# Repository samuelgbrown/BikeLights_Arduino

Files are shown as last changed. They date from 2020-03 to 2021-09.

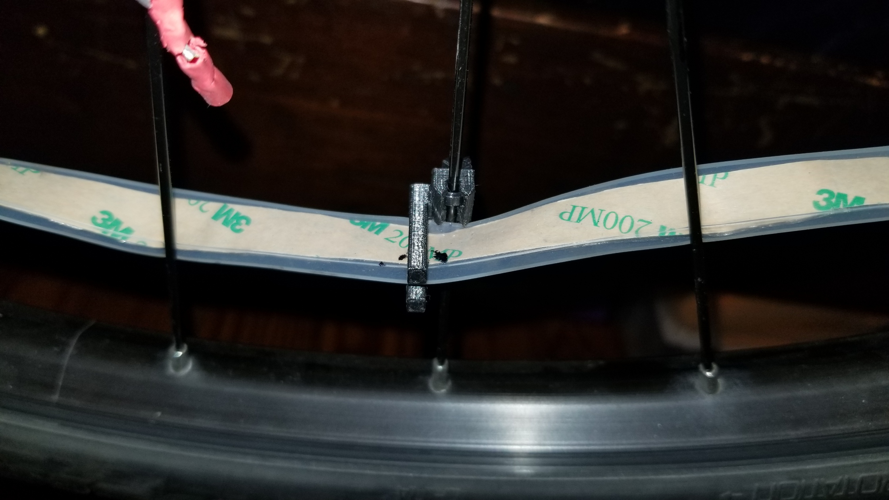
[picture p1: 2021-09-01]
pics/Suggested Guide Marks.jpg

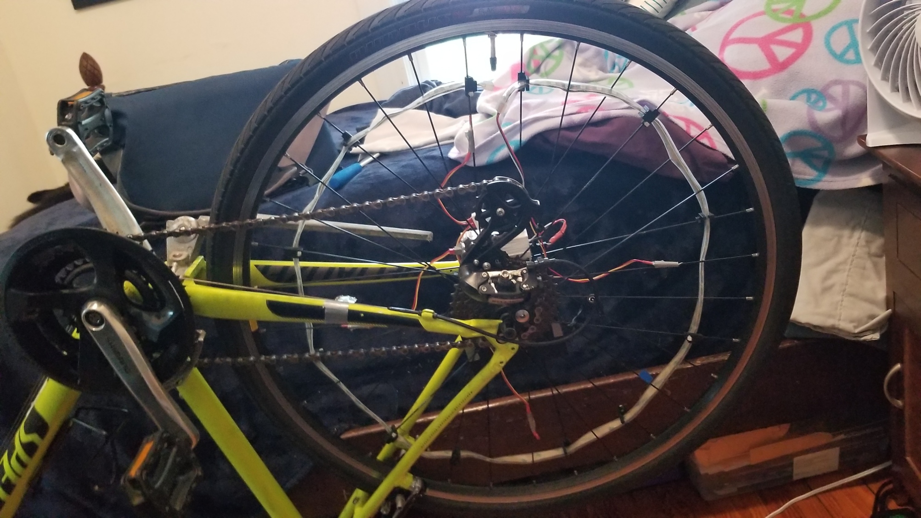
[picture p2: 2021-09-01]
pics/Full System.jpg

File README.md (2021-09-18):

# BikeLights_Arduino

"BikeLights" is a system to generate speed-sensitive light patterns on the edge of a bike's wheel.  It uses an Android device to design a pattern, and an Arduino system to display it on the wheel.

TODO:  Link to video

[See Android portion here](https://github.com/samuelgbrown/BikeLights_Android)

Arduino portion made using [PlatformIO](https://platformio.org/)!

# Theory of Operation
To use BikeLights, the user will design a custom lighting pattern on their Android phone using the Bike Lights app.  The user can then connect to the bluetooth adapter that is mounted on their bike wheel to send the lighting pattern to the LED's on the wheel.  The Arduino board on the wheel-mounted device will then display the designed pattern on the water-proof LED strip mounted along the rim of the wheel, using the information collected by the reed switches.

### 1. Bluetooth Communication protocol
The Android app and Arduino board must be able to communicate via bluetooth, despite the fact that their software is written in different languages.  Additionally, the memory constraints on the Arduino board necessitated writing a custom bluetooth protocol that would minimize the size of the message that must be stored on the Arduino during processing, while still allowing arbitrarily large messages to be received.  [The protocol design can be found here](https://github.com/samuelgbrown/BikeLights_Arduino/blob/master/bluetooth_protocol.txt).

### 2. Speed Detection
The position of the bike wheel is detected using a magnet mounted on the fork of the bike frame and some number N of reed switches mounted in an equiangular fashion around the wheel (see "[Sensors (standard)](https://github.com/samuelgbrown/BikeLights_Arduino/blob/master/Bike_Lights_refined_schem.png)").  The signals from all of the reed switches is treated in the same way, except for one (the "reference").  Each time a reed switch is closed, the signal is filtered through an RC circuit, and one of the hardware flip-flops is closed (one each for standard and reference, see "[RS Flip-Flop](https://github.com/samuelgbrown/BikeLights_Arduino/blob/master/Bike_Lights_refined_schem.png)").  A flip-flop is used so that interrupts are not required.

Once the Speedometer receives a signal from the reed switch (a "tic" or "reference tic"/"rTic"), the new measurement of position and velocity is fed to a [Kalman filter](https://en.wikipedia.org/wiki/Kalman_filter) calculating the wheel's [dead-reckoning](https://en.wikipedia.org/wiki/Dead_reckoning).  The Kalman filter's state variables are the wheel's position, speed, and acceleration in (LEDs, LEDs/s, LEDs/s^2), respectively.  For standard "tic"s, the new position is 1/N fraction of the distance around the wheel.  For "rTic"s, the new position is equal to the next "reference position" (i.e. the location of the wheel when the reference reed switch is aligned with the magnet).  Only one reference reed switch is used to save cost on hardware and space on the PCB.  Once the new measurement is added, the Kalman filter is propogated, and the new estimated position is used to calculate the new lighting position.

### 3. Pattern/Color_ Definition
The lighting on the wheel is defined by two constructs, the Color_ and the Pattern.

The Color_ represents the "paint", and is composed of individual colorObj objects.  Each colorObj represents an actual color (i.e. a hue represented by some combination of red/green/blue light).  A colorObj on its own is represented by a Color_Static object.  A color can then made to change with time (Color_dTime), or with wheel speed (Color_dVel).

The Pattern represents how the Color_ objects are arranged on the wheel.  Each LED can be painted with a Color_.  This pattern can be defined relative to the wheel (wheel speed independent) or relative to the ground (Pattern location changes dependent on wheel speed, to make it appear like it's not moving).  It each case, it can also have some constant angular velocity.  Finally, different patterns can be display in "idle" mode (when the wheel is moving too slowly to be measured by the speedometer) or "main" mode (when the wheel is moving at speed).

# Instructions for Use
Note that BikeLights only works on Android devices.

To set up BikeLights:
1. **Prepare** all materials
    1. **Prepare** Electronics
        1. **Purchase** the items on the Bill of Materials and any listed additional items (see below)
        2. **Prepare** a soldering workstation (including solder, wires, etc)
        3. **Solder** the breadboard according to the [bread board configuration](https://github.com/samuelgbrown/BikeLights_Arduino/blob/master/Bike_Lights_refined_bb.png) (see below for wire color legend), using the [schematic](https://github.com/samuelgbrown/BikeLights_Arduino/blob/master/Bike_Lights_refined_schem.png) for reference.
            1. **Prepare** 2 female 2-pin JST connectors with wires, to be used as connectors for the reed switches
        4. **Prepare** the 1-3 sensor connector adapter
            1. **Print** the [top half](https://github.com/samuelgbrown/BikeLights_Arduino/blob/master/models/1-to-3_Sensor_Connector_Adapter_Top_Final.stl) and [bottom half](https://github.com/samuelgbrown/BikeLights_Arduino/blob/master/models/1-to-3_Sensor_Connector_Adapter_Bottom_Final.stl) of the adapter case.
            2. **Crimp** a single male 2-pin JST connector to 3 female 2-pin JST connectors (in parallel).
            3. **Glue** this circuit of JST connectors in the adapter case (it will be a tight fit, but it will work).
            4. **Test** the connections of the connector adapter (using a test LED, a continuity tester, etc).
        5. **Prepare** the reed switch modules
            1. **Solder** 4 reed switches to wires in an ["inline" configuration](https://github.com/samuelgbrown/BikeLights_Arduino/blob/master/pics/Magnet.jpg) (wires should run along side the reed switch).  The 2 of the modules should have wire lengths of about 8" and 2 should have about 14".  Heat-shrink the exposed wires/solder.
            2. **Crimp** a male 2-pin JST connectors onto each module.
        7. **Prepare** the LED strip
            1. **Measure** the length of LED strip (and, most importantly, the number of LEDs) you will need to surround the circumference of your bike wheel.  Note that the BikeLights looks best when the LEDs are pushed as far towards the circumference of the wheel as possible, and are facing ["outward" from the wheel](https://github.com/samuelgbrown/BikeLights_Arduino/blob/master/pics/Reed%20Switch%20Positioning.jpg).
            2. **Cut** the LED strip to length.
            3. (Optional) **Repair** the waterproofing of the LED strip (using the LED strip waterproofing accessories, listed below), as needed.
            4. **Solder** any wires to the strip, as needed.
            5. (Optional) **Solder** an extension cable for the LED strip wires (a female 3-pin JST connector to a male 3-pin JST connector), that should be about 6" long.
    2. **Prepare** Arduino Software
        1. **Clone** this repo, and open in [PlatformIO](https://platformio.org/)
        2. **Customize** the [definitions in the software](https://github.com/samuelgbrown/BikeLights_Arduino/blob/master/include/Definitions.h#L65).  Specifically, set the number of reed switches you will use around the wheel (NUMSWITCHES), the number of LEDs you measured in the previous step (NUMLEDS, must be even), and the number of lights per LED (NUMLIGHTSPERLED, 3 for RGB lights, 4 for RGBW lights [note RGB lights may need some adjustment to work fully]).  You may also later want to customize the timing of the bit-banging for the LED control signal (T0H, T1H, T0L, T1L), using the system written by [bigjosh2 on wp.josh.com](https://wp.josh.com/2014/05/13/ws2812-neopixels-are-not-so-finicky-once-you-get-to-know-them/).
        3. **Flash** the software onto the Arduino Nano
    3. **Prepare** Arduino Device
        1. **Side-load** the [BikeLights_Android](https://github.com/samuelgbrown/BikeLights_Android) app onto your device.
        2. **Test** the system, by designing a light Pattern and sending it to the Arduino.  Use a button across the reed switch line or magnets to close the reed switchs themselves to send fake speed data to the system (note that, upon startup, the Arduino must see at least one reference tic [to locate the wheel's angular position] before starting the Main pattern).
    4. **Prepare** Bike wheel
        1. **Print** the [models for the mounting hardware](https://github.com/samuelgbrown/BikeLights_Arduino/tree/master/models).
            1. The number of [LED clips](https://github.com/samuelgbrown/BikeLights_Arduino/blob/master/models/Bike_Lights-LED_Strip_Clamp_Friction.stl) that you will need may vary.  For my mount, I used 12, but you want more or less.
            2. Use your own judgement for orientation when printing.  Keep in mind, however, that the cantilever clips operate best when printed in the correct orientation (i.e. such that bending does not separate the layers).  [See this website for more information](https://markforged.com/resources/blog/joinery-onyx) (go to header "Snap Fits").  For some parts, it will not be possible to print all of the clips in the optimal orientation.  ...Sorry.
        3. **Assemble** the parts.
            1. Place the soldered breadboard in its 3D printed case ([top](https://github.com/samuelgbrown/BikeLights_Arduino/tree/master/models/Bike_Lights_Case_Top_New_Final.stl) and [bottom](https://github.com/samuelgbrown/BikeLights_Arduino/tree/master/models/Bike_Lights_Case_Bottom_New_Final.stl)).  Attach any connectors to the breadboard, and glue these connectors to the top half of the case (the bottom should still be removable after gluing).
            2. Place the battery in its 3D printed case ([top](https://github.com/samuelgbrown/BikeLights_Arduino/tree/master/models/Bike_Lights_Battery_Case_Top_Final.stl) and [bottom](https://github.com/samuelgbrown/BikeLights_Arduino/tree/master/models/Bike_Lights_Battery_Case_Bottom_Final.stl)).
2. **Mount** The Hardware
    1. **Mount** the annular rings
        1. (Optional) **Tape** the insides of the rings with some double-sided tape, to aid adhesion to the central hub.
        2. **Orient** the halves of the ring around the hub how you would like them.  Note that the "[back ring](https://github.com/samuelgbrown/BikeLights_Arduino/blob/master/models/Bike_Lights-Annular_Ring_Back_Final.stl)" connects to the battery case, and the "[front ring](https://github.com/samuelgbrown/BikeLights_Arduino/blob/master/models/Bike_Lights-Annular_Ring_Front_Final.stl)" connects to the breadboard case.  It is recommended that you orient the rings such that the "front ring" is [facing a landmark on the wheel, such as the valve](https://github.com/samuelgbrown/BikeLights_Arduino/blob/master/pics/Main%20Case%202.jpg).
    2. **Mount** the LED strip
        1. **Position** the LED strip on the wheel.
        2. **Attach** the LED strip to the wheel using the LED clips.  Connect the clip to individual spokes by [mounting them to the desired spoke, and feeding a zip-tie through the clip](https://github.com/samuelgbrown/BikeLights_Arduino/blob/readme/pics/Magnet.jpg).  When finally positioned, tighten the zip-tie and cut off any extra.
        3. (Optional) [**Mark** the LED strip where the LED clips are touching it](https://github.com/samuelgbrown/BikeLights_Arduino/blob/master/pics/Suggested%20Guide%20Marks.jpg), for easier re-mounting later.
    3. **Attach** the battery and breadboard cases to the annular ring.  Note that the breadboard case has a specific orientation relative to the annular ring.
        1. **Secure** any unused wires on the battery (try [securely wrapping them around the spokes near the hub](https://github.com/samuelgbrown/BikeLights_Arduino/blob/master/pics/Main%20Case%202.jpg)).
        2. **Attach** the 1-3 connector adapter to the "standard switch" port on the breadboard case.
    4.  **Mount** the reed switch modules to the spokes of the wheel.
        1.  **Position** the modules such that they are [equally spaced around the wheel](https://github.com/samuelgbrown/BikeLights_Arduino/blob/master/pics/Full%20System.jpg).  The module that will become the "reference" should be oriented such that it is going over the portion of the fork that will hold the magnet when the wheel is oriented "upwards".  Also keep in mind the amount of wire required to connect the module back to the breadboard case.
        2.  **Tape** the modules to the wheel in these positions.  Note that they should all be about the same radius away from the hub.
        3.  **Mount** the magnets to the bike fork, [such that they will be close to the reed switches as the wheel rotates](https://github.com/samuelgbrown/BikeLights_Arduino/blob/master/pics/Magnet.jpg).  Note that a bit of trial and error will be required here (see Debug The System), as you may find that the reed switch may be most sensitive to the magnet at the edges of the module rather than dead center (see [picture reference](https://github.com/samuelgbrown/BikeLights_Arduino/blob/master/pics/Magnet.jpg)).
    5.  **Connect** all components
        1. **Plug** in the three standard reed switch modules to the 1-3 sensor connector adapter.
        2. **Plug** in the reference reed switch module to the reference sensor port on the breadboard case.
        3. **Plug** in the LED strip (optionally using the ~6" extension cable that you may have made) to the LED strip port on the breadboard case.
        4. **Plug** in the battery to the DC power port on the breadboard case.
    6. **Secure** the system
        1. **Test** how well connected the various parts of the system are, and add duct tape where necessary to reduce rattle and keep everything in place.
4. **Debug** The System
    1. **Rejoice** that you should now have a fully functional BikeLights system!  However, if something has gone wrong, consider the following debug steps.
    2. **Connect** to the Arduino's debug screen
        1. **Download** a bluetooth terminal for your Android device (I use [S2 Terminal for Bluetooth](https://m.apkpure.com/s2-terminal-for-bluetooth-free/jp.side2.apps.btterm), but consider any Bluetooth terminal application).
        2. **Connect** to the Arduino using the bluetooth terminal.
        3. **Send** the character "d" for the debug screen.
            1. "Tic debugging" - This will send a message to your bluetooth terminal every time a reed switch module is activated.  Also differentiates between "standard tics" and "reference tics".
            2. "Block extra reference tics" - This will prevent extra reference signals being sent, by requiring that at least one "standard tic" is detected between registering "reference tics".
            3. "Block extra standard tics" - This will block any extra "standard tics" being sent between "reference tics".
            4. "Use adaptive debouncing" (obsolete - incorporated) - This flag used to enable the adaptive debouncing feature that has since been merged.  It now enables some information about the adaptive debouncing.
        4. **Send** the character corresponding to the desired debug mode (such as "d1" for "Tic debugging").
    3. **Test** the reed switch positioning and functionality.  Try rigging an LED to light when the reed switch is closed.  A spare magnet can be used to check that they work, and the bike-mounted magnet can be used to confirm that they are being triggered correctly.
    4. **Design** a "location test" pattern on the Arduino device to send.  A good test of the actual position is setting only a single pixel at a time to be active.

# Adapting for Your Own Bike
BikeLights was custom made for my bike wheel (a Specialized 28" wheel [700x32c]), but it should be possible to adapt to your own needs.  To adapt to your own bike, consider changing the following:
* The mounting system
    * This will likely be the most difficult part.
    * You should adapt the annular ring (both the [front](https://github.com/samuelgbrown/BikeLights_Arduino/blob/master/models/Bike_Lights-Annular_Ring_Front_Final.stl) and [back](https://github.com/samuelgbrown/BikeLights_Arduino/blob/master/models/Bike_Lights-Annular_Ring_Back_Final.stl) models).  The inner curvature of these models will likely need to be changed.  If any of the geometry of the connection system to the battery case or breadboard cases is changed, make sure to make complimentary changes to the [top](https://github.com/samuelgbrown/BikeLights_Arduino/blob/master/models/Bike_Lights_Battery_Case_Top_Final.stl) and [bottom](https://github.com/samuelgbrown/BikeLights_Arduino/blob/master/models/Bike_Lights_Battery_Case_Bottom_Final.stl) halves of the battery cases and/or the [top](https://github.com/samuelgbrown/BikeLights_Arduino/blob/master/models/Bike_Lights_Case_Top_New_Final.stl) and [bottom](https://github.com/samuelgbrown/BikeLights_Arduino/blob/master/models/Bike_Lights_Case_Bottom_New_Final.stl) halves of the breadboard case.
    * Make sure that you will still be able to get the battery/breadboard cases between the spokes, and that there will be room for them inside of the wheel.
* The defined number of LEDs, and the number of reed switches (as described in "Prepare Arduino Software" -> "Customize", above).

# Electronics / Hardware
[Hardware Bill of Materials](https://htmlpreview.github.io/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)

(Note 1: This BOM (and the following) is to make ONE system for ONE bike wheel.  Consider doubling where necessary to make a pair.)

(Note 2: for reed switches, they must be NO switches (normaly open).  Also, I recommend getting some that have a plastic case around them, for longevity.)

Additionally:
  * ~2m per wheel WS2812B (or equivalent) RGBW LED strip, preferably with IP67 waterproofing
  * (Optionally) Various LED strip waterproofing accessories
      * [Waterproof Sealant](https://www.superbrightleds.com/moreinfo/adhesives/wfls-gl1oz-1-oz-waterproof-sealant-tube/861/2135/)
      * [Extra silicone tubing](https://www.superbrightleds.com/moreinfo/waterproofing/st10-10mm-silicone-tubing/869/2142/) (probably 10mm)
      * [Extra silicone end-caps](https://www.superbrightleds.com/moreinfo/waterproofing/10mm-silicone-end-cap/864/2138/)
      * [Extra silicone end-caps with wire holes](https://www.superbrightleds.com/moreinfo/waterproofing/10mm-silicone-end-cap-4-holes/866/2140/)
  * [2-pin "JST" connectors](https://www.aliexpress.com/item/32872148939.html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)
  * (Optionally) 3-pin "JST SM" connectors for WS2812B WS2811 WS2812 SK6812 LED strips
  * Small lot (~5) of 5.5x2.1mm DC power plug (male and female)
  * 1x 12V Lithium ion battery pack (I used 6800 mAh)
  * Required wire (potentially two types, see Bread Board Configuration below)
  * 1x (4"x6") Prototype PCB / solderable bread-board
  * Neodymium Magnet(s)
  * Bag of small zip-ties (2mm wide will fit in the [LED clips](https://github.com/samuelgbrown/BikeLights_Arduino/blob/master/models/Bike_Lights-LED_Strip_Clamp_Friction.stl))
  * A healthy dose of duct tape

[Schematic](https://github.com/samuelgbrown/BikeLights_Arduino/blob/master/Bike_Lights_refined_schem.png) (please forgive some of the upside-down values...)

[Bread Board Configuration](https://github.com/samuelgbrown/BikeLights_Arduino/blob/master/Bike_Lights_refined_bb.png)
  * Blue, black, and red are standard-gauge (20-22 AWG) wires
  * Green are fine gauge (36 AWG) wires
    * Note these are a bit difficult to work with
  * Pink are solder blobs

[Models for mounting hardware](https://github.com/samuelgbrown/BikeLights_Arduino/tree/master/models)

[Reference pictures of installation](https://github.com/samuelgbrown/BikeLights_Arduino/tree/master/pics)

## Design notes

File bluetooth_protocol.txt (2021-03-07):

This file is scratch-space for designing the byte-code that will represent the information transfered between Arduino and Android.
Every bit will be represented as a one- or two-character symbol.  A byte that represents a single piece of information when interpretted together will be represented as a one- or two- character symbol preceded by "b_"

The message will be encoded per-byte.  The following is a breakdown per byte of the information encoded.
If any message being sent from Android to Arduino does not fit in 64 bytes, then it will be broken into as many 62-byte messages (n <= 2^4) as required to fit it.  The first two bytes will be filled in according to the pattern below, otherwise subsequent messages will pick up where the last left off.

Maximum values enforced by this standard:
Message size (Android to Arduino):  64B (dependant on Serial buffer size of Arduino)
Message size (Arduino to Android):  Unlimited
Number of messages:                 15 (TT, S)
Number of LEDs:                     255 (N)
Size of palette:                    255 (PC)
Number of colorObj_meta:            255 (NC)

The right-most bit the lowest significance (as if it were written out by hand), should be little endian (?)
e.g. 1 = [0 0 0 0 0 0 0 1]

# # # # # # # # # # # # # # # # # # # # # # # # #
- R C1 C2 C3 CF X X X | [TT1 TT2 TT3 TT4 S1 S2 S3 S4] | []-
R (bool) - 1 if the message is requesting an update from the system regarding information about the content implied by C (S) will be disregarded).  0 if the message contains information
C (3uint) - A numerical representation of the type of information contained in this message, when interpretted as an unsigned integer
    0 - Bike Wheel Animation
    1 - Kalman information
    2 - Brightness scale value
    3 - Storage information
    4 - Battery information
    5 - Power state information
CF (bool) - 1 if the message is a confirmation of a previously sent message, sent when the Arduino is ready for the next message; only first 2 bytes are sent (only used in Arduino->Android communication, to confirm that a 64-byte message was just received).  If CF = true, then the next byte will be the last byte of the message (2 bytes total)
X - Unused
The second byte will be sent iff the message is a confirmation (CF = true) OR the message is being sent from Android to Arduino
TT (4uint) - The number of 64-byte messages required to convey this information
S (4uint) - The number of this message in the sequence up to T messages (If CF is true, S is the number of the message just received)

From here, the content of the remainder of the message depends on the type of message:
# # # # # # # # # # # # # # # # # # # # # # # # #

# # # # # # # # # # # # # # # # # # # # # # # # #
C == 0 : Bike Wheel Animation
- N1 N2 N3 N4 N5 N6 N7 N8 | PC1 PC2 PC3 PC4 PC5 PC6 PC7 PC8 -
N (8uint) - The number of LEDs on the bike wheel that are being considered
PC (8uint) - The size of the Color_ object palette

Each Color_ object will be encoded in the following way:
- CT1 CT2 CT3 CT4 X X X X | [] -
CT (4uint) - Color_ type
    0 - Static Color_
    1 - Time-based Color_
    2 - Velocity-based Color_

    # # # # # # # # # # # # # # # # # # # # # # #
    CT == 0: Static Color_
    The next bytes will be only the RGBW representations of the color
    - b_R | b_G | b_B | b_W -
    R, B, G, W (8uint) - The brightness of the indicated LED for this color

    # # # # # # # # # # # # # # # # # #4 # # # # #
    CT == 1 or CT == 2: Time-based Color_ AND Velocity-based Color_
    - b_NC -
    NC (8uint) - The number of colorObj_meta's that will be encoded in the following bytes

    Each colorObj_meta will be represented by the following bytes:
    - b_R | b_G | b_B | b_W | b_B | b_T1 b_T2 b_T3 b_T4 - 
    R, B, G, W (8uint) - The brightness of the indicated LED for this color
    B (8uint) - The blend-type that this colorObj_meta uses
        0 - Constant
        1 - Linear
    T (4ulong for time-based/4float for vel-based) - The T value of this colorObj_meta, represented as 4-bytes to be interpreted according to the type of Color_ that holds this colorObj
    # # # # # # # # # # # # # # # # # # # # # # #

The Image information will be encoded in the following way:
- X X X SI ITM1 ITM2 ITM3 ITM4 | b_IPM | (N/2) x b_IM | [b_ITI | b_IPI | (N/2) x b_II] -
SI (bool) - Does the image support an idle image? 1 if yes, 0 if no
ITM (4uint) - The Image Type for the main image.
    0 - Wheel_rel_rot (constant rotation, relative to the wheel)
    1 - Ground_rel_rot (constant rotation, relative to the ground)
    2 - Spinner (rotation behaves like a spinner hub-cap)
IPM (8sint) - The parameter set for the main Image, dependant on ITM
    0 - IPM represents the rotation rate
    1 - IPM represents the rotation rate
    2 - IPM represents the inertia
IM (byte) - The image values for the main image.  Each half byte (nibble) represents the index in the palette that this LED is colored.  There are N/2 bytes in this portion

IF SI == 1, the bytes in the bracket will be used.  Otherwise, they are excluded.
ITI (8uint) - The Image Type for the idle image
    0 - Wheel_rel_rot (constant rotation, relative to the wheel)
IPM (8sint) - The parameter set for the idle Image, dependant on ITI
    0 - The rotation rate
II (byte) - The image values for the idle image.  Each half byte (nibble) represents the index in the palette that this LED is colored.  There are N/2 bytes in this portion

# # # # # # # # # # # # # # # # # # # # # # # # #

# # # # # # # # # # # # # # # # # # # # # # # # #
C == 1 : Kalman
- NO1 NO2 NO3 NO4 ST1 ST2 ST3 ST4 | b_Q1 b_Q2 b_Q3 b_Q4 | [NO*NO x b_R1 b_R2 b_R3 b_R4] | [ST*ST x b_P1 b_P2 b_P3 b_P4] -
NO (4uint) - Number of observation variables (2 - position, velocity)
ST (4uint) - Number of state variables (3 - position, velocity, acceleration)
Q (4float) - Q, as a scalar
R (4float[]) - NO x NO matrix, interpreted as columns first, then rows (i.e. send each row individually, in column order)
P (4float[]) - ST x ST matrix, interpreted as columns first, then rows (i.e. send each row individually, in column order)
# # # # # # # # # # # # # # # # # # # # # # # # #

# # # # # # # # # # # # # # # # # # # # # # # # #
C == 2 : Brightness scale
- b_BF1 b_BF2 b_BF3 b_BF4 -
BF (4float) - Brightness factor, less than or equal to 1, and greater than 0.
# # # # # # # # # # # # # # # # # # # # # # # # #

# # # # # # # # # # # # # # # # # # # # # # # # #
C == 3 : Storage
- b_RE1 b_RE2 b_RE3 b_RE4 | b_TO1 b_TO2 b_TO3 b_TO4 -
RE (4ulong) - The amount of remaining RAM
TO (4ulong) - The amount of total RAM
# # # # # # # # # # # # # # # # # # # # # # # # #

# # # # # # # # # # # # # # # # # # # # # # # # #
C == 4 : Battery
- b_BA -
BA (8uint) - The amount of battery remaining, out of 255.
# # # # # # # # # # # # # # # # # # # # # # # # #

# # # # # # # # # # # # # # # # # # # # # # # # #
C == 5 : Power [NOTE: NOT YET IMPLEMENTED IN ARDUINO]
- [P X X X X X X X -
P (bool) - The power state of the LED strip, i.e. whether or not the LED's are on or not (0 = off)
# # # # # # # # # # # # # # # # # # # # # # # # #

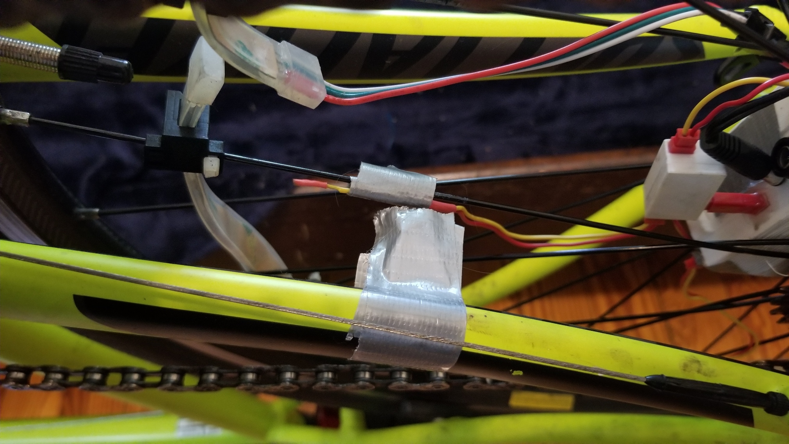
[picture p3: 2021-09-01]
pics/Magnet.jpg

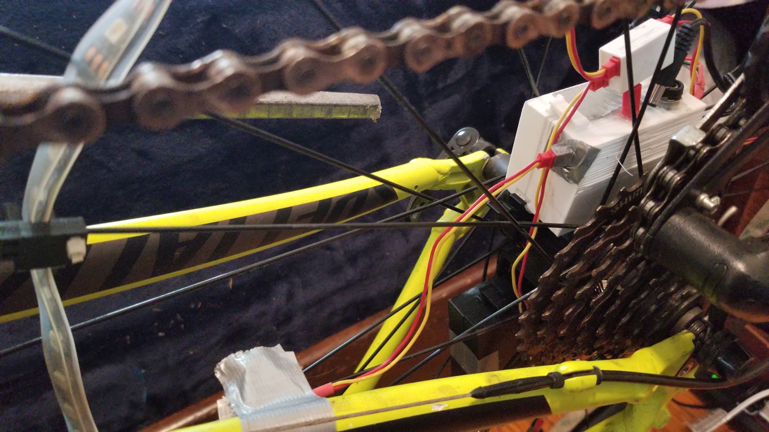
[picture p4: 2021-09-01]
pics/Main Case 03.jpg

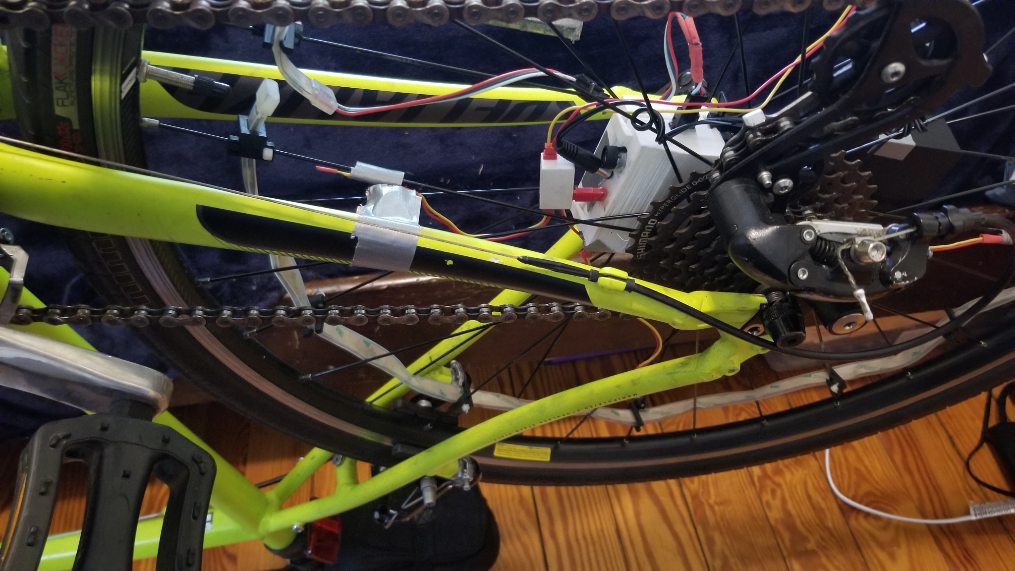
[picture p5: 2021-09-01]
pics/Reed Switch Positioning.jpg

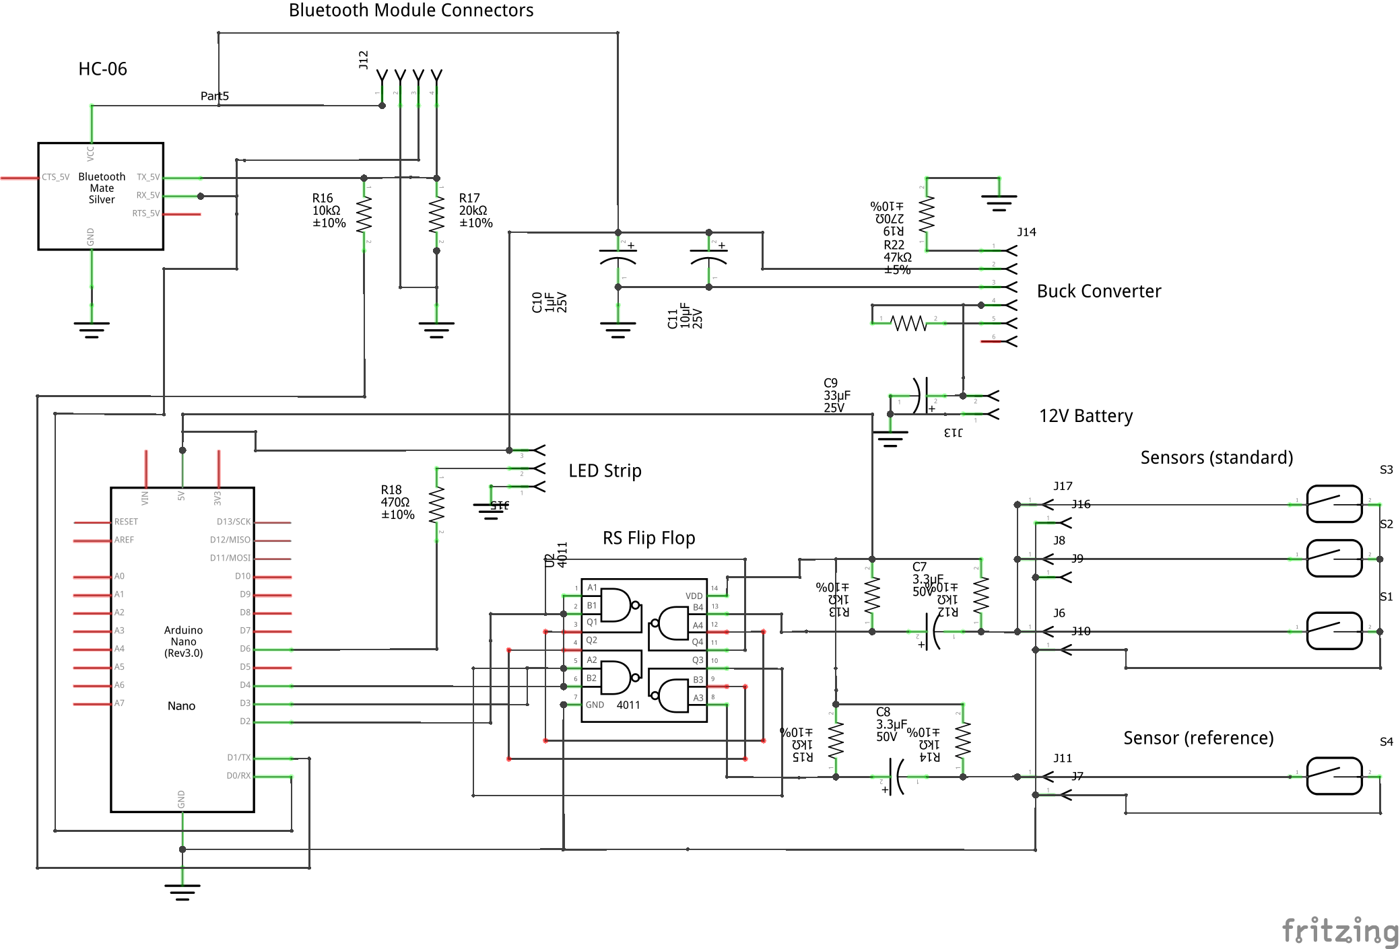
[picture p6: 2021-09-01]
Bike_Lights_refined_schem.png

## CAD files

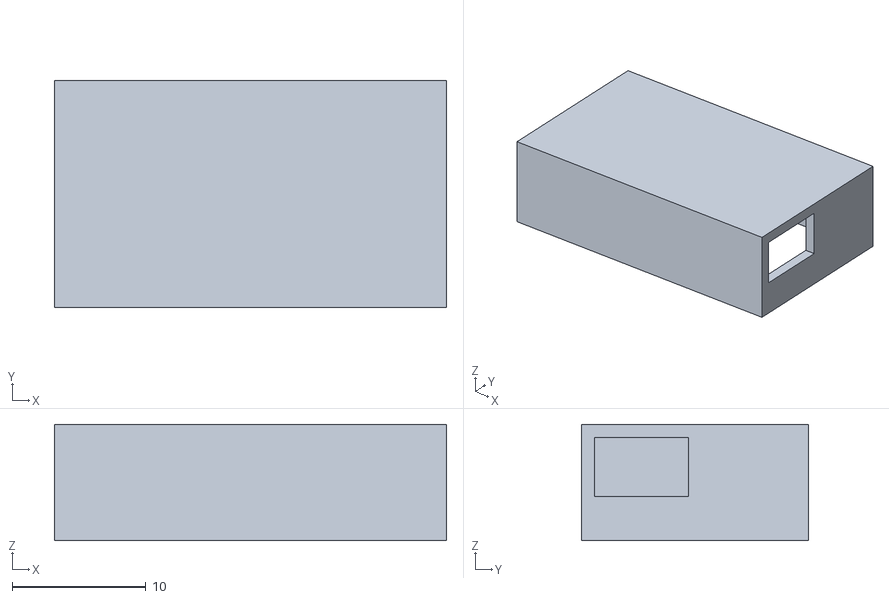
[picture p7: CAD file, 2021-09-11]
models/1-to-3_Sensor_Connector_Adapter_Top_Final.stl
29.3 x 17.0 x 8.70

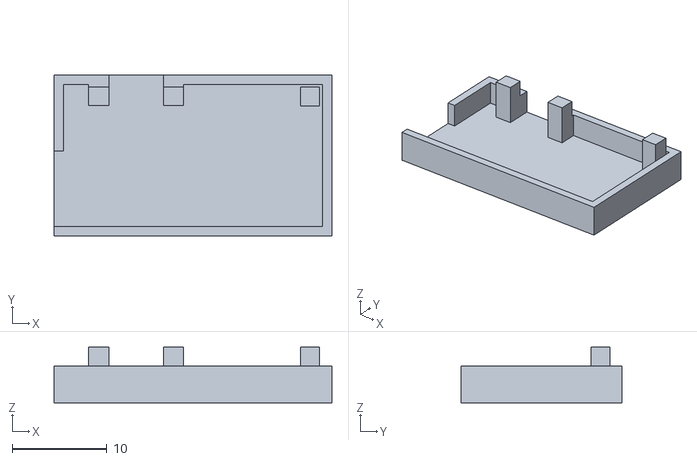
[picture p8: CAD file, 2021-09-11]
models/1-to-3_Sensor_Connector_Adapter_Bottom_Final.stl
29.3 x 17.0 x 5.86

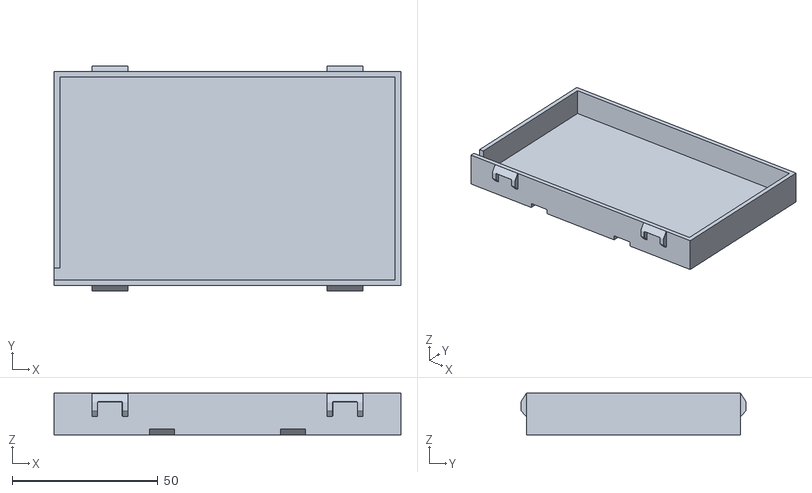
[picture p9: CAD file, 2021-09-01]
models/Bike_Lights_Battery_Case_Bottom_Final.stl
119.0 x 77.3 x 14.3

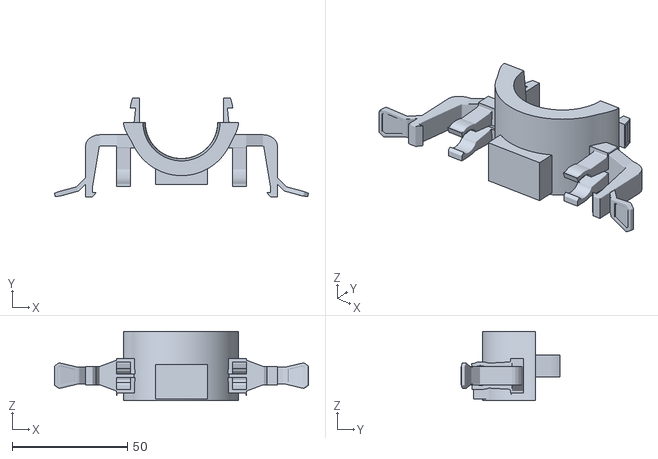
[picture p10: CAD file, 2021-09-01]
models/Bike_Lights-Annular_Ring_Front_Final.stl
110.0 x 42.9 x 30.0

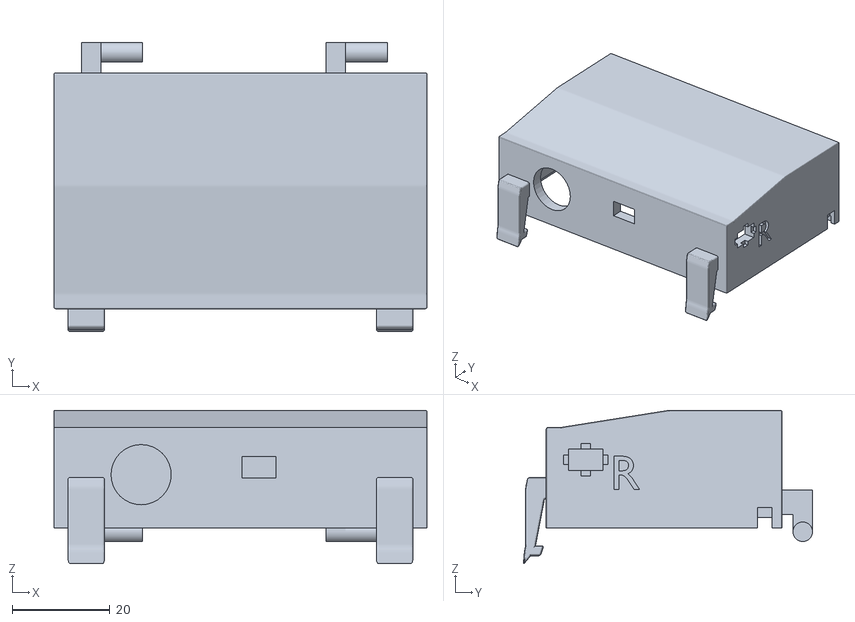
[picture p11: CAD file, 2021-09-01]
models/Bike_Lights_Case_Top_New_Final.stl
76.2 x 59.1 x 31.3

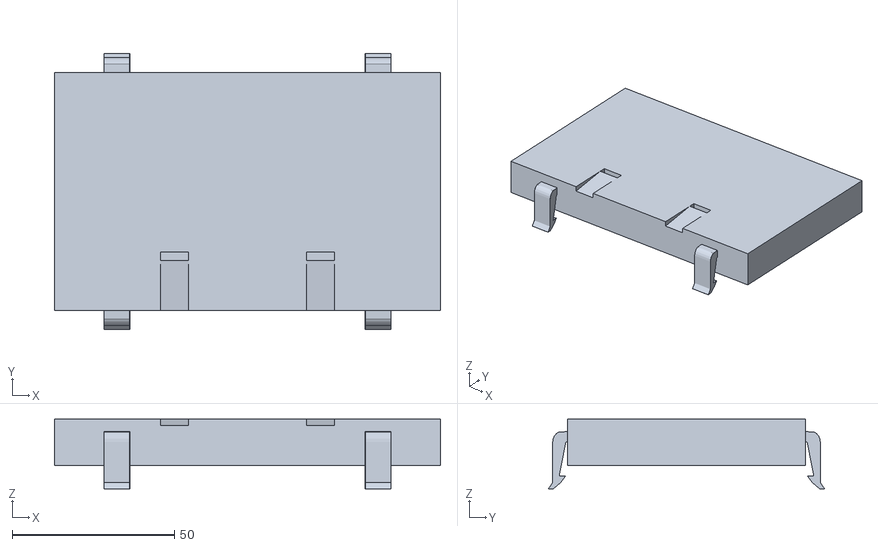
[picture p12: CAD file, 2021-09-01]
models/Bike_Lights_Battery_Case_Top_Final.stl
119.0 x 85.2 x 21.6

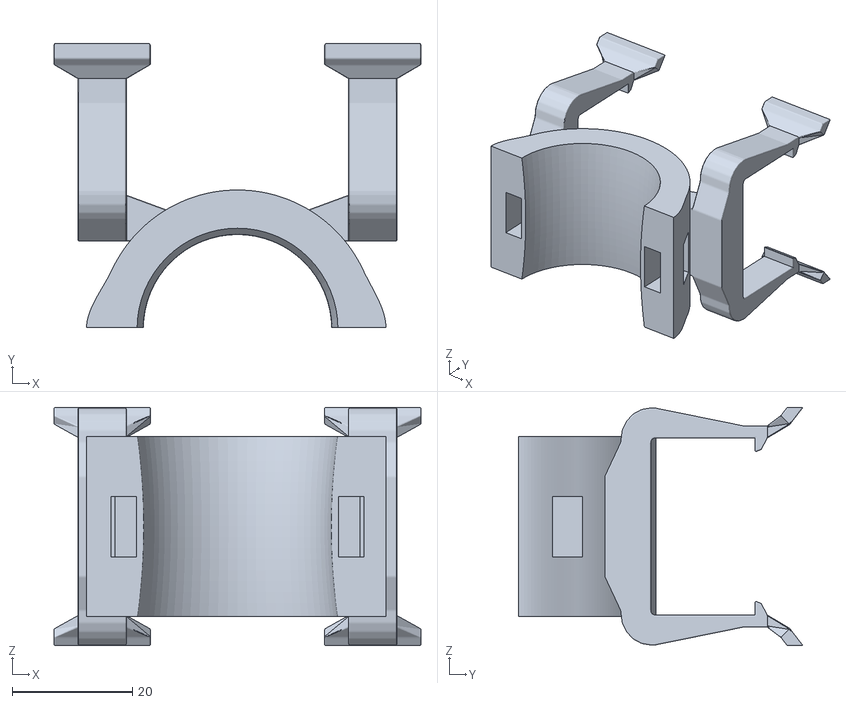
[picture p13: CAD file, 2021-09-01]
models/Bike_Lights-Annular_Ring_Back_Final.stl
61.0 x 47.3 x 39.6

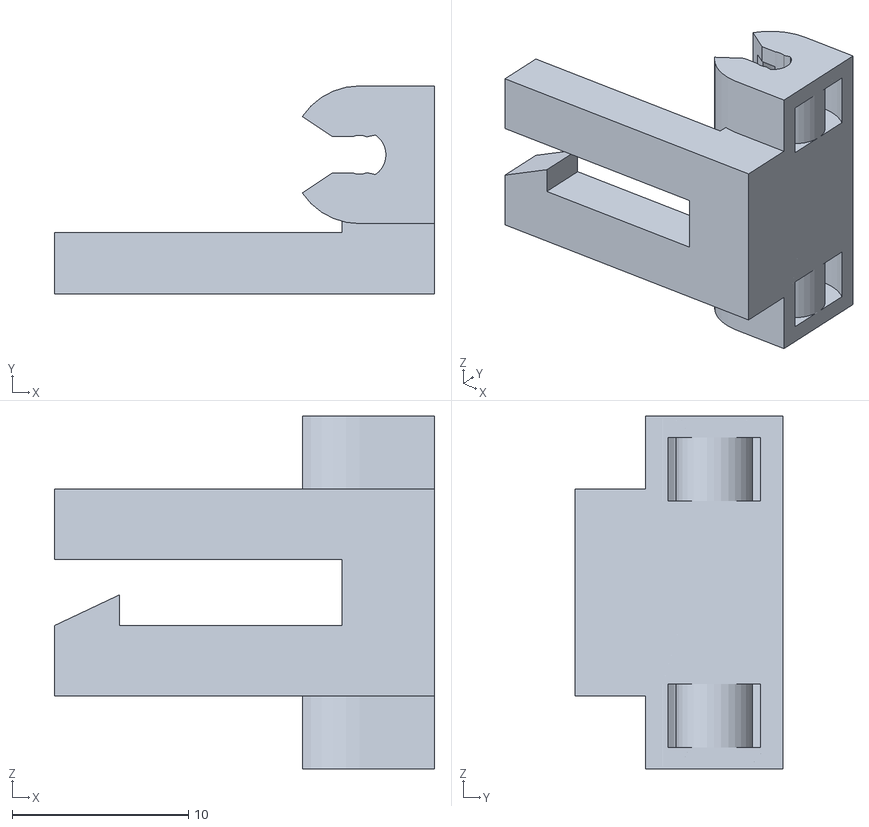
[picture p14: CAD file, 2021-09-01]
models/Bike_Lights-LED_Strip_Clamp_Friction.stl
21.5 x 11.8 x 20.0

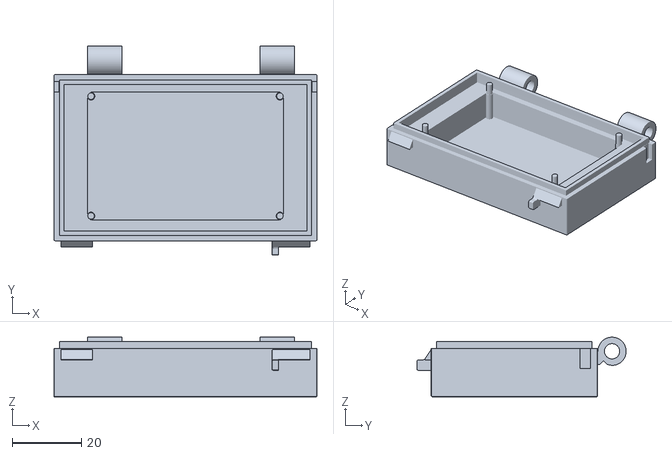
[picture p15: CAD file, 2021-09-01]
models/Bike_Lights_Case_Bottom_New_Final.stl
76.2 x 60.7 x 17.3

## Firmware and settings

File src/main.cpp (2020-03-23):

#include "Speedometer.h"
#include "Pattern.h"
#include "Definitions.h"
#include "Color.h"
#if !NO_BLUETOOTH
#include "Bluetooth.h"
#endif

//void tickISR() {
//  // Global scope wrapper function for the Speedometer's member function (Just a member function to keep everything nicely grouped)
//  Speedometer::tic();
//}
//
//void rTickISR() {
//  // Global scope wrapper function for the Speedometer's member function (Just a member function to keep everything nicely grouped)
//  Speedometer::rTic();
//}

//Speedometer speedometer = Speedometer(tickISR, rTickISR);
int outOfScopeRam = freeRam();
Speedometer *speedometer = NULL;
Pattern_Handler *pattern_handler = NULL; // Make a generic pattern object
#if !NO_BLUETOOTH
Bluetooth *bluetooth = NULL;
#endif

// TODO: DEBUGGING
Pattern *idlePat = NULL; // Used for debugging

void setup()
{
  // Set up power
  pinMode(POWERPIN, OUTPUT);
  digitalWrite(POWERPIN, HIGH); // Enable the VRAE-10E1A0 connected to POWERPIN

  // Set up debugging
  if (DEBUGGING_ANY)
  {
    Serial.begin(9600);
    Serial.flush();
    delay(100);
  }

  if (DEBUGGING_ANY)
  {
    //    Serial.flush();
    Serial.println();
    Serial.println();
    Serial.println(F("***"));
    Serial.println(F("*********"));
    Serial.println(F("Starting setup..."));
    Serial.println(F("*********"));
    Serial.println(F("***"));
    delay(100);
    Serial.print(F("Initial memory: "));
    Serial.println(outOfScopeRam);
    //    randomSeed(analogRead(0));
    //    Serial.println(random(1000));
  }

  if (!LIBRARY_TEST)
  {

    // float newQ;

    if (DEBUGGING_GENERAL)
    {
      //    Serial.flush();
      Serial.println();
      Serial.println(F("Making Speedometer..."));
      Serial.println(freeRam());
    }

    // Set up Speedometer
    speedometer = new Speedometer();
    // if (DEBUGGING_Q)
    // {
    //   speedometer->getKalman()->setPhi(newQ);
    // }

    if (!UNITTEST_SPEEDOMETER)
    {
      if (DEBUGGING_GENERAL)
      {
        //    Serial.flush();
        Serial.println(F("Making Pattern Handler..."));
        Serial.print(F("Current memory: "));
        Serial.println(freeRam());
        Serial.println();
      }

      // Set up a Pattern Handler
      pattern_handler = new Pattern_Handler(speedometer); // Make a generic pattern object

      if (DEBUGGING_GENERAL)
      {
        //    Serial.flush();
        Serial.println(F("Made Pattern Handler..."));
        Serial.print(F("Current memory: "));
        Serial.println(freeRam());
        Serial.println();
      }

#if !NO_BLUETOOTH
      if (DEBUGGING_GENERAL)
      {
        //    Serial.flush();
        Serial.println(F("Making Bluetooth..."));
        Serial.print(F("Current memory: "));
        Serial.println(freeRam());
        Serial.println();
      }

      // Set up a Bluetooth object
      bluetooth = new Bluetooth(pattern_handler, speedometer);

      if (DEBUGGING_GENERAL)
      {
        //    Serial.flush();
        Serial.println(F("Made Bluetooth..."));
        Serial.print(F("Current memory: "));
        Serial.println(freeRam());
        Serial.println();
      }
#endif
    }
  }
  else
  {
    //
    //// Library test script
    //

    for (int i = 0; i < 1000; i++)
    {
      if (DEBUGGING_ANY)
      {
        Serial.flush();
        Serial.print(F("Making idle pattern "));
        Serial.println(i);
        Serial.print(F("Current memory: "));
        Serial.println(freeRam());
        Serial.println();
      }

      // Create a still idle image
      // idlePat = new Still_Image_Idle();

      if (DEBUGGING_ANY)
      {
        Serial.flush();
        Serial.print(F("Made idle pattern "));
        Serial.println(i);
        Serial.print(F("Current memory: "));
        Serial.println(freeRam());
        Serial.println();
        Serial.println(F("Deleting idle pattern..."));
        Serial.println();
      }

      delete idlePat;

      if (DEBUGGING_ANY)
      {
        Serial.flush();
        Serial.print(F("Deleted idle pattern "));
        Serial.println(i);
        Serial.print(F("Current memory: "));
        Serial.println(freeRam());
        Serial.println();
      }
    }
  }

  if (DEBUGGING_ANY)
  {
    //    Serial.flush();
    Serial.println(F("Set finished."));
    Serial.print(F("Current memory: "));
    Serial.println(freeRam());
    Serial.println();
    Serial.println();
    delay(100);
    //    delay(1000);
  }
};

void loop()
{
  if (!LIBRARY_TEST)
  {
    if (DEBUGGING_GENERAL)
    {
      Serial.println(F("Speedometer loop..."));
      //      Serial.print(F("nLEDs is "));
      //      Serial.println(speedometer->kalman.checkNumLEDs());
      //    delay(500);
    }
    //  while (1) {};
    // Execute the Speedometer's main loop (determine the current orientation of the wheel)
    speedometer->mainLoop();

    if (!UNITTEST_SPEEDOMETER)
    {
      if (DEBUGGING_GENERAL)
      {
        Serial.println(F("Pattern loop..."));
        Serial.print(F("Current memory: "));
        Serial.println(freeRam());
        Serial.println();
        //    delay(500);
      }
      // Execute the Pattern' main loop
      pattern_handler->mainLoop();
      

#if !NO_BLUETOOTH
      if (DEBUGGING_GENERAL)
      {
        Serial.println(F("Bluetooth Loop..."));
        Serial.print(F("Current memory: "));
        Serial.println(freeRam());
        Serial.println();
        //    delay(500);
      }
      // Execute the Bluetooth main loop
      bluetooth->mainLoop();
#endif
    }

    if (DEBUGGING_GENERAL)
    {
      Serial.println();
    }
  }
  else
  {
    //
    //// Library test loop
    //

    //    idlePat->anim();
    //    controller::show_LEDs();
  }
};

// float getNewQ()
// {
//   //  Serial.flush();
//   Serial.println(F("What is Q?"));
//   String inString = "";
//   float finalVal = 0;
//   while (finalVal <= 0)
//   {
//     //    while (Serial.available() == 0) {}
//     while (Serial.available() > 0)
//     {
//       int inChar = Serial.read();
//       if (inChar != '\n')
//       {
//         inString += (char)inChar;
//         //        Serial.println(inString);
//       }
//       else
//       {
//         finalVal = inString.toFloat();
//         inString = "";
//         if (finalVal <= 0)
//         {
//           //          Serial.flush();
//           Serial.print(F("Please enter valid positive value for Q (Q = "));
//           //          Serial.flush();
//           Serial.print(finalVal);
//           //          Serial.flush();
//           Serial.println(").");
//         }
//         break;
//       }
//     }
//   }

//   //  Serial.flush();
//   Serial.print(F("Q = "));
//   //  Serial.flush();
//   Serial.println(finalVal);
//   return finalVal;
// };

int freeRam()
{
  extern int __heap_start, *__brkval;
  int v;
  return (int)&v - (__brkval == 0 ? (int)&__heap_start : (int)__brkval);
};

// Define nibble operations (to deal with the image field, which has two image locations stored in each byte)

unsigned char valFromFirstNibble(unsigned char fullByte)
{
  // Get an int representation of the first nibble

  // Mask out to get only the first nibble (lowest significance half), and return the resulting value as an unsigned char
  return (unsigned char)(FIRST_NIBBLE_MASK & fullByte);
}

unsigned char valFromSecondNibble(unsigned char fullByte)
{
  // Get an int representation of the second nibble

  // Bit-shift the second nibble (highest significance half) into the lowest significance half, leaving 0's in the high significance place
  return (unsigned char)fullByte >> 4;
}

void valToFirstNibble(unsigned char valToSet, unsigned char &fullByte)
{
  // Set a value to the first nibble in fullByte
  // (Assuming that valToSet <= 16, without checks)

  // Mask out to get only the second nibble, then set the first nibble to valToSet
  fullByte = (unsigned char)((SECOND_NIBBLE_MASK & fullByte) | valToSet);
}

void valToSecondNibble(unsigned char valToSet, unsigned char &fullByte)
{
  // Set a value to the second nibble in fullByte
  // (Assuming that valToSet <= 16, without checks)

  // Mask out to get only the first nibble, then set the second nibble to valToSet (by bit-wise or-ing with a bit-shifted valToSet)
  fullByte = (unsigned char)((FIRST_NIBBLE_MASK & fullByte) | valToSet << 4);
}

void serialPrintColor(unsigned char color[NUMLIGHTSPERLED])
{
    Serial.print(F("[ "));
    for (int i = 0; i < NUMLIGHTSPERLED; i++)
    {
        Serial.print(color[i]);
        Serial.print(F(" "));
    }
    Serial.print(F("]"));
}

void printByte(unsigned char byteToPrint)
{
  if (DEBUGGING_ANY) {
    Serial.print(F("[ "));

    for (int i = 7; i >= 0; i--)
    {
      Serial.print((byteToPrint >> i) & 1);
      Serial.print(" ");
    }

    Serial.println(F("]"));
  }
}

void printColorBytes(unsigned char * colorBytes) {
  if (DEBUGGING_ANY) {
    Serial.print(F("RGBW: ["));
    Serial.print(colorBytes[0]);
    Serial.print(F(", "));
    Serial.print(colorBytes[1]);
    Serial.print(F(", "));
    Serial.print(colorBytes[2]);
    Serial.print(F(", "));
    Serial.print(colorBytes[3]);
    Serial.print(F("]"));
  }
}

void printColorObj(colorObj color) {
  if (DEBUGGING_ANY) {
    Serial.print(F("RGBW: ["));
    Serial.print(color.r());
    Serial.print(F(", "));
    Serial.print(color.g());
    Serial.print(F(", "));
    Serial.print(color.b());
    Serial.print(F(", "));
    Serial.print(color.w());
    Serial.print(F("]"));
  }
}

int posMod(int k, int n) {
  return ((k%=n) < 0) ? (k + n) : k;
}

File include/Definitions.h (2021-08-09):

#ifndef Definitions_h
#define Definitions_h

/*

  Track all of the definitions in this project, useful for defining the sizes and configurations for hardware and the like.

  Samuel G. Brown
  July 16 2017

*/
//
//// Code differences based on hardware
//
// SHOULD BE TRUE
#define BLUETOOTH_USE_HARDWARESERIAL true // Should the HardwareSerial connection on the Arduino be used for communicating with the Bluetooth connection (should be used when not debugging, if possible)
#define TIC_USE_LATCH true                 // Should the "tics" (position switches) be attached via an SR latch (alternative: they are attached via interrupts)

// FALSE UNTIL FURTHER NOTICE
#define SRAM_ATTACHED false                // Is SRAM attached to this unit?  If so, then certain memory intensive computations, such as blurring, can be done
#define USE_NANOPB false                   // Should we use the nanoPB library (currently unusable due to severe FRAM limitations, ~10KB over the 32KB limit)
#define COLORD_COPY_ARRAYS false           // Should the Color_d<T>::setupArrays() function copy input arrays (takes more memory), or take ownership of new arrays that come in (arrays CANNOT be deleted by calling function)


// Optional code differences based on software
// SHOULD BE TRUE
#define USE_LOWERROR_PPOST true     // Should PPost be calculated in such a way as to reduce rounding errors (will use more RAM during the calculation, should be 4*(3*3 + 2*(2*3)) = 84 bytes)
#define USE_THREE_STATE_KALMAN true // Should the Kalman filter track three states (position + velocity + acceleration) instead of two (- acceleration)?
#define USE_VEL_MEASUREMENT true    // Should the Kalman filter accept velocities as measurements from the switches, or only positions?

// Schematic of the latch:
//
// Reed Switch (through high-pass)-- S        Q ---- Tic    |
//                                    \      /              |
//                                     FlipFlop             |
//                                    /      \              |
// Reset (output from Arduino)------ R        ~Q ---        |

// Unit testing
#define UNITTEST_SPEEDOMETER false // Should only the speedometer be created and tested?
#define LIBRARY_TEST false         // Should a single script be run instead of the normal function (to test singular parts of the library)?
#define NO_BLUETOOTH false         // Try compiling without any Bluetooth code...just cuz

// Debugging
#define DEBUGGING_GENERAL false            // Breakdown every step that the software takes
#define DEBUGGING_PATTERN false            // Debug the pattern processing
#define DEBUGGING_MOVINGIMAGE false        // Debug the moving image functions
#define DEBUGGING_DYNAMICCOLOR false       // Debug the dynamic color main functions
#define DEBUGGING_SPINNER false             // Debug the spinner pattern
#define DEBUGGING_SPEEDOMETER false        // Debug the speedometer
#define DEBUGGING_KALMAN false             // Debug the kalman filter
#define DEBUGGING_Q false                  // Experiment with different Q's
#define DEBUGGING_TIC false                 // See when the Arduino sees a tic
#define DEBUGGING_MEASUREMENT false         // See what measurements the arduino recieves
#define DEBUGGING_SPEED false              // See what speed the arduino thinks the wheel is going
#define DEBUGGING_BLUETOOTH false          // Debug the bluetooth connection
#define DEBUGGING_PATTERN_SIZE false       // Debug the memory allocation of the pattern object
#define DEBUGGING_BLUETOOTH_LOWLEVEL false // Debug the bluetooth connection
#define DEBUGGING_BTDEBUG false             // Debug the Bluetooth debugging interface
// #define DEBUGGING_ANY !BLUETOOTH_USE_HARDWARESERIAL && (DEBUGGING_GENERAL || DEBUGGING_Q || DEBUGGING_DYNAMICCOLOR || DEBUGGING_TIC || DEBUGGING_MEASUREMENT || DEBUGGING_SPINNER || DEBUGGING_SPEED || DEBUGGING_PATTERN || DEBUGGING_SPEEDOMETER || DEBUGGING_KALMAN || UNITTEST_SPEEDOMETER || DEBUGGING_BLUETOOTH || LIBRARY_TEST)
#define DEBUGGING_ANY (DEBUGGING_GENERAL || DEBUGGING_Q || DEBUGGING_DYNAMICCOLOR || DEBUGGING_TIC || DEBUGGING_MEASUREMENT || DEBUGGING_SPINNER || DEBUGGING_SPEED || DEBUGGING_PATTERN || DEBUGGING_SPEEDOMETER || DEBUGGING_KALMAN || UNITTEST_SPEEDOMETER || DEBUGGING_BLUETOOTH || DEBUGGING_BTDEBUG || LIBRARY_TEST)

// These are the only two interrupt pins that can be used for an external interrupt request
// Process can be sped up by using pin change interrupt and attaching interrupt by hand, using pins from different batches: https://arduino.stackexchange.com/questions/1784/how-many-interrupt-pins-can-an-uno-handle
#define TICKPIN 2
#define RTICKPIN 3
#define RESETTICKPIN 4 // Used with SR latch - common reset signal to both latches
#define POWERPIN 5
#define BLUETOOTHPIN_TX_TO_BT_RX 9
#define BLUETOOTHPIN_RX_TO_BT_TX 8
#define NUMSWITCHES 4
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

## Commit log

2019-05-28 First commit from "Backup" Arduino project
2019-07-12 About to convert all images to one-LED-per-nibble
2019-08-16 About to redesign Pattern
    [Bluetooth.cpp, Pattern.h]
2019-11-29 Currently testing bluetooth (incoming done?)
2020-02-04 Mostly functional (has memory leak on BWA update)
    [Bluetooth.cpp, Definitions.h, Pattern.cpp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]
2020-05-29 Fixed Spinner, other fixes and reorganizations
    [Bluetooth.cpp, Color.cpp, Definitions.h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]
2021-09-01 Added 3D models and reference pictures
    [Bike_Lights-Annular_Ring_Back_Final.stl, Bike_Lights-Annular_Ring_Front_Final.stl, Bike_Lights-LED_Strip_Clamp_Friction.stl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]
